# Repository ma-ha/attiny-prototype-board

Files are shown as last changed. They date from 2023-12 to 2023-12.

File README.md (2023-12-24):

# ATtiny Prototype Board v2

Simplifies circuit prototypying with the ATtiny xx14.

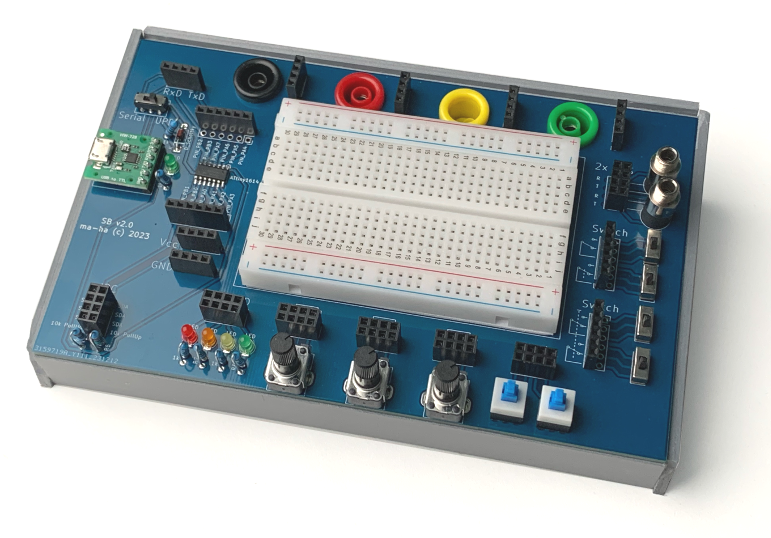
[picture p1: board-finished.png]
1stBuild
 

Features:
- Beadboard (400 pins)
- I/O
  - 4x LED
  - 3x Potentiometer
  - 2x momentary push button
  - 4x Switch
  - 2x 3.5 mm TRS socket
  - 4x banana socket
  - 2/3x I2C
  - 2x Serial
- ATtiny XX14
- FTDI adapter (CH340E Micro USB Serial adapter)
  - UPDI programming
  - USB power
  - Serial debugging

Videos:
- Build: https://youtu.be/CmCrIgkOkTU (no talking)
- Description https://youtu.be/84AR5vEIgwg (German)

# Links

- megaTinyCore Core: https://github.com/SpenceKonde/megaTinyCore
- ATtiny xx14 Pinout https://github.com/SpenceKonde/megaTinyCore/blob/master/megaavr/extras/ATtiny_x14.md
- Installation in Arduino IDE: https://github.com/SpenceKonde/megaTinyCore/blob/master/Installation.md

# Release Notes

## v2.1 changes

Improvements:
- Switch (optional) for I2C
- I2C labels and lines
- Push buttons with opener and closer funtionality
- Moved USART 

Fixes: 
- banana sockets were too close to border
- more space between switches and TRS

## v2.0 changes

- use THT LEDs, resistors, diode
- use slide switch: more reliable and visible
- use only socket header

# Blink All

Use this "blink" code to check proper soldering for all ATtiny pins:

    // BLINK ALL ATtiny xx14

    void setup() {
      pinMode( PIN_PA4, OUTPUT );
      pinMode( PIN_PA5, OUTPUT );
      pinMode( PIN_PA6, OUTPUT );
      pinMode( PIN_PA7, OUTPUT );
      pinMode( PIN_PB3, OUTPUT );
      pinMode( PIN_PB2, OUTPUT );
      
      pinMode( PIN_PB1, OUTPUT );
      pinMode( PIN_PB0, OUTPUT );
      pinMode( PIN_PA0, OUTPUT );
      pinMode( PIN_PA1, OUTPUT );
      pinMode( PIN_PA2, OUTPUT );
      pinMode( PIN_PA3, OUTPUT );
      Serial.begin( 9600 );
    }

    void loop() {
      digitalWrite( PIN_PA4, HIGH );   
      digitalWrite( PIN_PA5, HIGH );   
      digitalWrite( PIN_PA6, HIGH );   
      digitalWrite( PIN_PA7, HIGH );   
      digitalWrite( PIN_PB3, HIGH );   
      digitalWrite( PIN_PB2, HIGH );
        
      digitalWrite( PIN_PB1, HIGH );   
      digitalWrite( PIN_PB0, HIGH );   
      digitalWrite( PIN_PA0, HIGH );   
      digitalWrite( PIN_PA1, HIGH );   
      digitalWrite( PIN_PA2, HIGH );   
      digitalWrite( PIN_PA3, HIGH );   
      Serial.println( "on" );
      delay( 500 );                       
      
      digitalWrite( PIN_PA4, LOW );   
      digitalWrite( PIN_PA5, LOW );   
      digitalWrite( PIN_PA6, LOW );   
      digitalWrite( PIN_PA7, LOW );   
      digitalWrite( PIN_PB3, LOW );   
      digitalWrite( PIN_PB2, LOW );
        
      digitalWrite( PIN_PB1, LOW );   
      digitalWrite( PIN_PB0, LOW );   
      digitalWrite( PIN_PA0, LOW );   
      digitalWrite( PIN_PA1, LOW );   
      digitalWrite( PIN_PA2, LOW );   
      digitalWrite( PIN_PA3, LOW );   
      Serial.println( "off" );
      delay( 500 );                     
    }

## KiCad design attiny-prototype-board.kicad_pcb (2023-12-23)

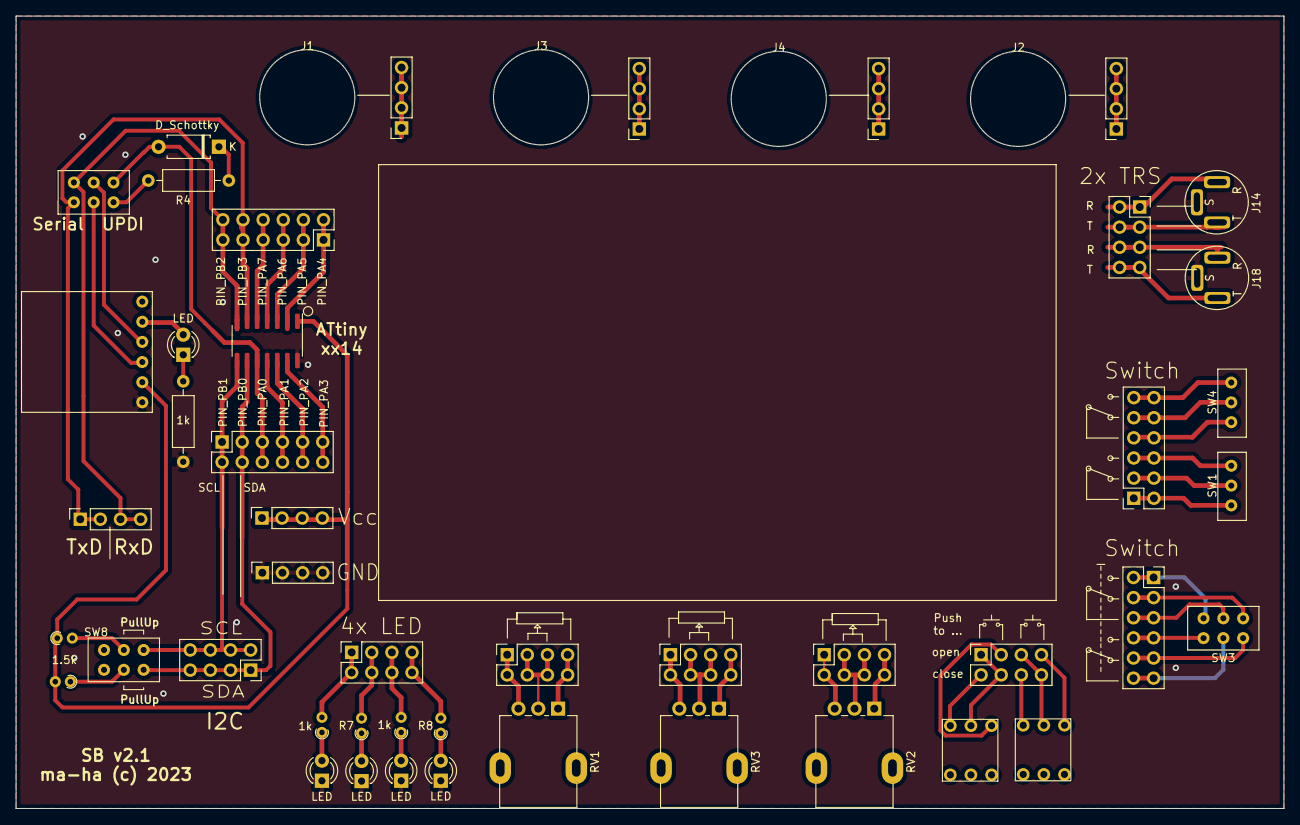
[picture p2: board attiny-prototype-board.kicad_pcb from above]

Board: 2 copper layers, 160.0 x 100.0 mm, 50 parts (0 on the bottom side), 65 nets.

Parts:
1k: 1k; R_Axial_DIN0207_L6.3mm_D2.5mm_P10.16mm_Horizontal
D1, D2, D3, D5, D6: LED; LED_D3.0mm
D4: D_Schottky; D_A-405_P7.62mm_Horizontal
J1, J2, J3, J4: Banana
J5, J7, J8: tinyRight; PinSocket_2x06_P2.54mm_Vertical
J6, J15, J19, J22: toPoti; PinSocket_2x04_P2.54mm_Vertical
J9, J10, J11, J12: banana; PinSocket_1x04_P2.54mm_Vertical
J13: tinyLeft; PinSocket_2x06_P2.54mm_Vertical
J14, J18: TRS35; Stereo3.5
J16: toAudio; PinSocket_2x04_P2.54mm_Vertical
J17: USART; PinSocket_1x04_P2.54mm_Vertical
J20: GND; PinSocket_1x04_P2.54mm_Vertical
J21: toBtn; PinSocket_2x04_P2.54mm_Vertical
J23: VCC; PinSocket_1x04_P2.54mm_Vertical
J25: I2C; PinSocket_2x04_P2.54mm_Vertical
R1, R2, R7, R8: 1k; R_Axial_DIN0204_L3.6mm_D1.6mm_P1.90mm_Vertical
R4: 1k; R_Axial_DIN0207_L6.3mm_D2.5mm_P10.16mm_Horizontal
R5, R6: 1.5k; R_Axial_DIN0204_L3.6mm_D1.6mm_P1.90mm_Vertical
RV1, RV2, RV3: R_POT; Potentiometer_Single_Vertical
SW1, SW4: SW_SPDT; Switch_SPDT_1P2T
SW2: Switch UPDI; Switch_SPDT_2P2T
SW3, SW8: 2x Switch; Switch_SPDT_2P2T
SW9, SW10: SW_Push_DPDT; PushBtn6x6
U1: FTDI-Adapter; FTDI
U2: ATtinyXX14-SS; SOIC-14_3.9x8.7mm_P1.27mm

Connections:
FTDI-RXD: SW2.2, U1.3
FTDI-TXD: SW2.5, U1.4
GND: 1k.1, D1.1, D2.1, D5.1, D6.1, J14.2, J18.2, J20.1, J20.2, J20.3, J20.4, U1.6, U2.14
unnamed: D1.2, R1.1
unnamed: D2.2, R7.1
unnamed: 1k.2, D3.1
unnamed: D3.2, U1.2
unnamed: D4.1, R4.1
unnamed: D5.2, R2.1
unnamed: D6.2, R8.1
unnamed: J9.1, J9.2, J9.3, J9.4
unnamed: J5.1, J5.2, SW1.1
unnamed: J5.3, J5.4, SW1.2
unnamed: J5.5, J5.6, SW1.3
unnamed: J5.7, J5.8, SW4.1
unnamed: J5.9, J5.10, SW4.2
unnamed: J5.11, J5.12, SW4.3
unnamed: J6.1, J6.2, R1.2
unnamed: J6.3, J6.4, R7.2
unnamed: J6.5, J6.6, R2.2
unnamed: J6.7, J6.8, R8.2
unnamed: J8.1, J8.2, SW3.6
unnamed: J8.3, J8.4, SW3.4
unnamed: J8.5, J8.6, SW3.5
unnamed: J8.7, J8.8, SW3.3
unnamed: J8.9, J8.10, SW3.1
unnamed: J8.11, J8.12, SW3.2
unnamed: J10.1, J10.2, J10.3, J10.4
unnamed: J11.1, J11.2, J11.3, J11.4
unnamed: J12.1, J12.2, J12.3, J12.4
unnamed: J14.1, J16.3, J16.4
unnamed: J14.3, J16.1, J16.2
unnamed: J15.1, J15.2, RV1.3
unnamed: J15.3, J15.4, J15.5, J15.6, RV1.2
unnamed: J15.7, J15.8, RV1.1
unnamed: J16.5, J16.6, J18.3
unnamed: J16.7, J16.8, J18.1
unnamed: J19.1, J19.2, RV2.3
unnamed: J19.3, J19.4, J19.5, J19.6, RV2.2
unnamed: J19.7, J19.8, RV2.1
unnamed: J21.1, J21.4, SW10.2
unnamed: J21.2, SW10.1
unnamed: J21.3, SW10.3
unnamed: J21.5, J21.8, SW9.2
unnamed: J21.6, SW9.1
unnamed: J21.7, SW9.3
unnamed: J22.1, J22.2, RV3.3
unnamed: J22.3, J22.4, J22.5, J22.6, RV3.2
unnamed: J22.7, J22.8, RV3.1
unnamed: R4.2, SW2.6
unnamed: R5.1, SW8.5
unnamed: R6.2, SW8.2
RXD: J13.11, J13.12, J17.3, J17.4, SW2.1, U2.7
SCL: J7.1, J7.2, J25.2, J25.4, J25.6, J25.8, SW8.3, U2.8
SDA: J7.3, J7.4, J25.1, J25.3, J25.5, J25.7, SW8.6, U2.9
TXD: J13.9, J13.10, J17.1, J17.2, SW2.4, U2.6
TinyP1: J13.1, J13.2, U2.2
TinyP2: J13.3, J13.4, U2.3
TinyP3: J13.5, J13.6, U2.4
TinyP4: J13.7, J13.8, U2.5
TinyP9: D4.2, J7.5, J7.6, SW2.3, U2.10
TinyP10: J7.7, J7.8, U2.11
TinyP11: J7.9, J7.10, U2.12
TinyP12: J7.11, J7.12, U2.13
VCC: J23.1, J23.2, J23.3, J23.4, R5.2, R6.1, U1.5, U2.1

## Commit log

2023-12-16 v2 publish
    [attiny-prototype-board.kicad_pcb, attiny-prototype-board.sch]
2023-12-16 fix lib path
    [attiny-prototype-board.sch]
2023-12-23 v2.1 some improvements
    [attiny-prototype-board.kicad_pcb, attiny-prototype-board.sch]
2023-12-23 v2.1 move USART
    [attiny-prototype-board.kicad_pcb, attiny-prototype-board.sch]

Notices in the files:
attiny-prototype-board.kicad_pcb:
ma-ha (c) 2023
